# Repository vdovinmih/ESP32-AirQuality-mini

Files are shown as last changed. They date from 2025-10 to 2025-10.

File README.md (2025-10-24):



# ESP32-AirQuality-mini
AirQuality zigbee mini sensor ESP32

Цели и задачи устройства:
1. измерять температуру, влажность, и показатель качества воздуха (TVOС)
2. по протоколу zigbee передавать эти показания в систему умного дома на основе z2m
3. [опция] выступать роутером в zigbee сети
4. [опция] передавать измеренные значения напрямую в устройства одной zigbee сети минуя координатор и сервер умного дома

Основные комплектующие: 
1. ESP32- C6/H2 SuperMini 
https://aliexpress.ru/item/1005006907067134.html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
https://aliexpress.ru/item/1005008148472502.html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
https://github.com/Zektopic/esp32-h2-supermini-kicad?ysclid=memrikceaz898473666
* H2 
https://www.espboards.dev/esp32/esp32-h2-super-mini/
* C6 
https://www.espboards.dev/esp32/esp32-c6-super-mini/

3. Датчик температуры и влажности AHT10 (i2c)
https://aliexpress.ru/item/1005008699139931.html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

4. AGS10 Модуль обнаружения газа (i2c)
https://aliexpress.ru/item/1005008593136272.html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

5. [опция] на площадки модуля B+ B- опционально можно подключить 3.7в LiIon АКБ совмещённый с модулем защиты
https://aliexpress.ru/item/1005004304618610.html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

на модули датчиков питание 3.3в подаётся с ESP32-H2, +2 пина i2c, я использовал (H2 модуль) 13, 14. Но 13 нога висит в паралель с диодом. Лучше использовать другую пару например 11,12
 
Питание устройства:
1. Интегрированный на ESP32 модуле разъём usb-c
2. пара клемм на 12 вольт (при наличии преобразователя 12в -> 5в), опционально делитель для измерения
3. для измерения напряжения батареи нужен делитель. 50/50
4.

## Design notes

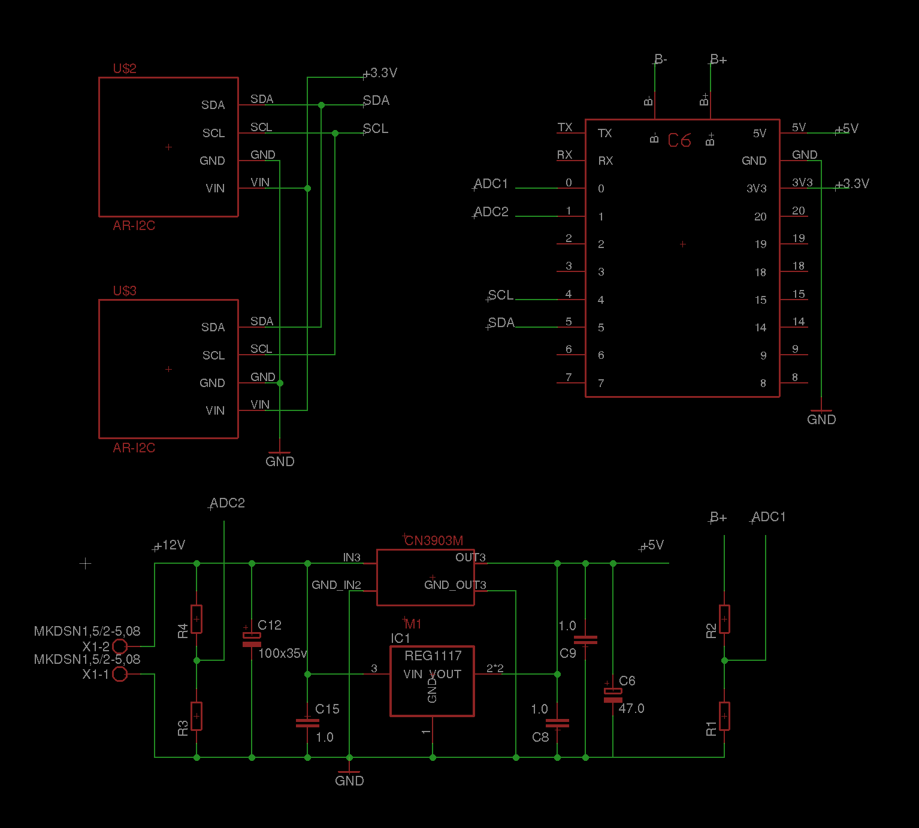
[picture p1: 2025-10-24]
HW/schematic.png

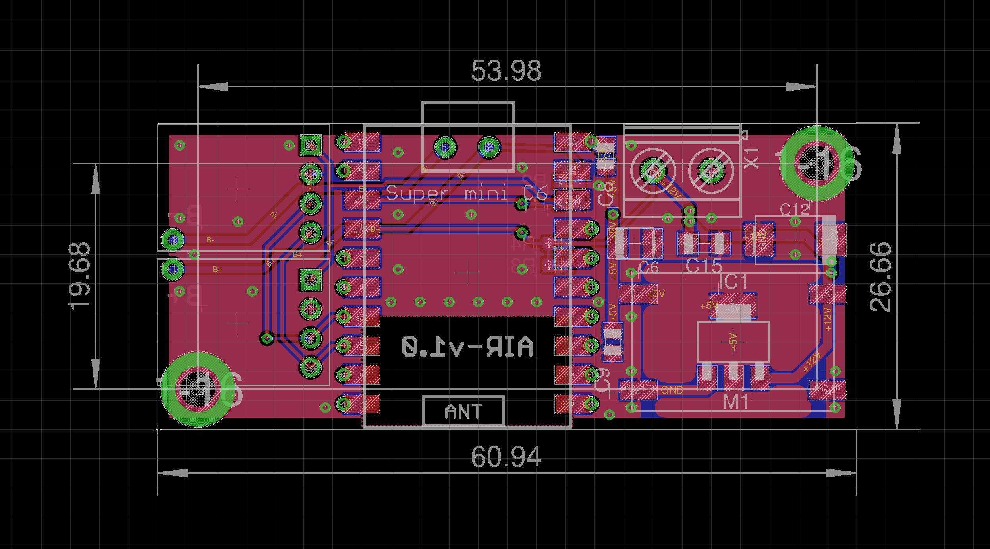
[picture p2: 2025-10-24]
HW/main-v1.0.png

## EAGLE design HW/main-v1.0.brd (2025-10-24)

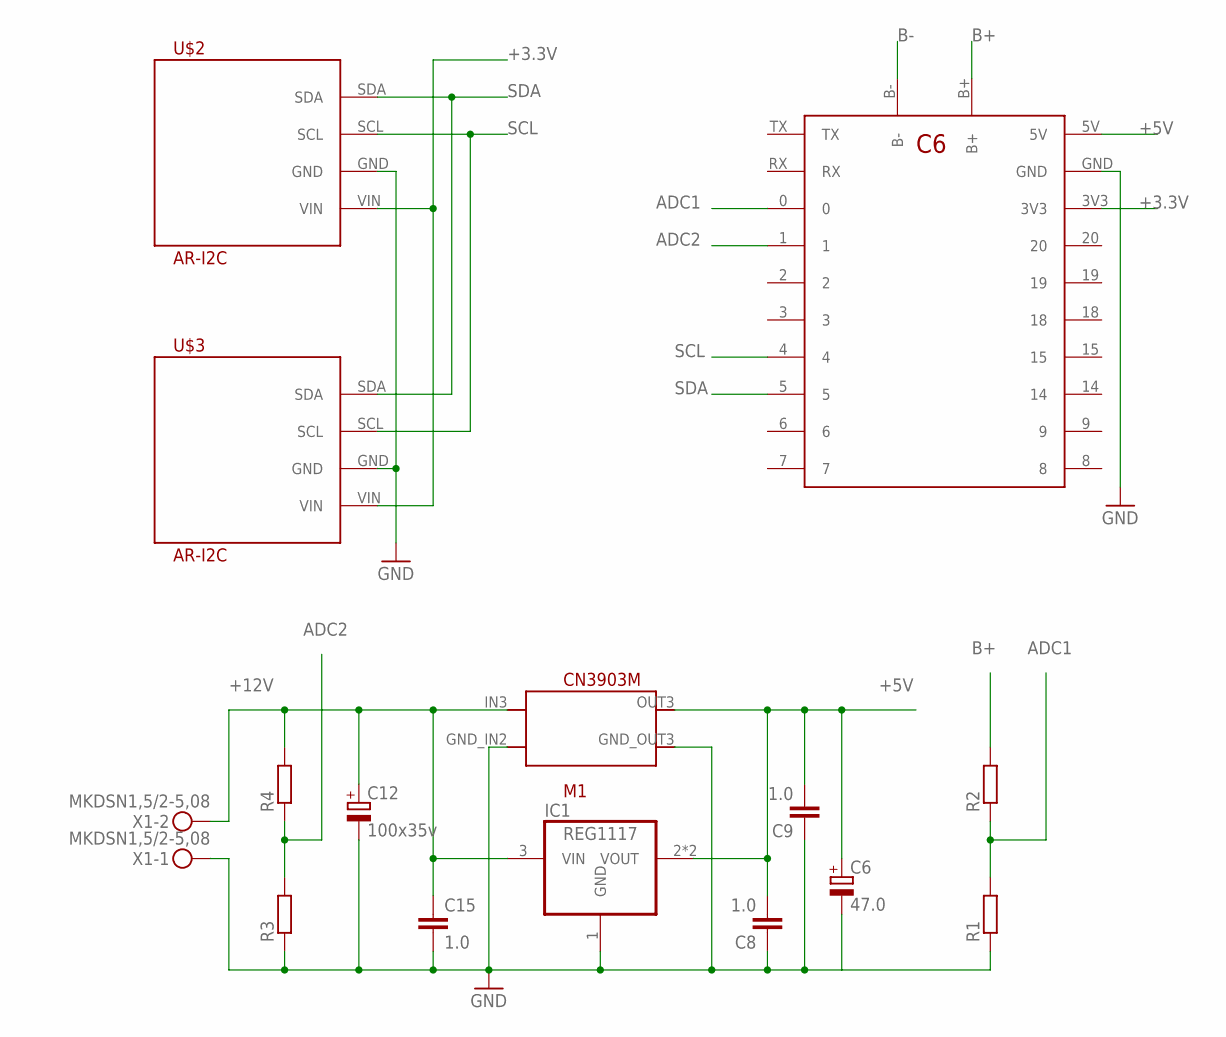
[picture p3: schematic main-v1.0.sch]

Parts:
C6: 47.0; SMC_B
C8, C9: 1.0; C0805
C12: 100x35v; SMC_E
C15: 1.0; C1206
IC1: REG1117; SOT223
M1: CN3903M
R1, R2, R3, R4: R-EU_R0603; R0603
U$1: ESP32-C6-SM; ESP32-C6-SUPER-MINI
U$2, U$3: AR-I2C
X1: MKDSN1,5/2-5,08

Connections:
+3.3V: U$1.3V3, U$2.VIN, U$3.VIN
+5V: C6.+, C8.2, C9.2, IC1.2 (VOUT), IC1.4 (VOUT), M1.OUT3 (OUT), U$1.5V
+12V: C12.+, C15.1, IC1.3 (VIN), M1.IN3 (IN), R4.2, X1.2
ADC1: R1.2, R2.1, U$1.0
ADC2: R3.2, R4.1, U$1.1
B+: R2.2, U$1.B+
B-: U$1.B-
GND: C6.-, C8.1, C9.1, C12.-, C15.2, IC1.1 (GND), M1.GND_IN2 (GND_IN), M1.GND_OUT3 (GND_OUT), R1.1, R3.1, U$1.GND, U$2.GND, U$3.GND, X1.1
SCL: U$1.4, U$2.SCL, U$3.SCL
SDA: U$1.5, U$2.SDA, U$3.SDA

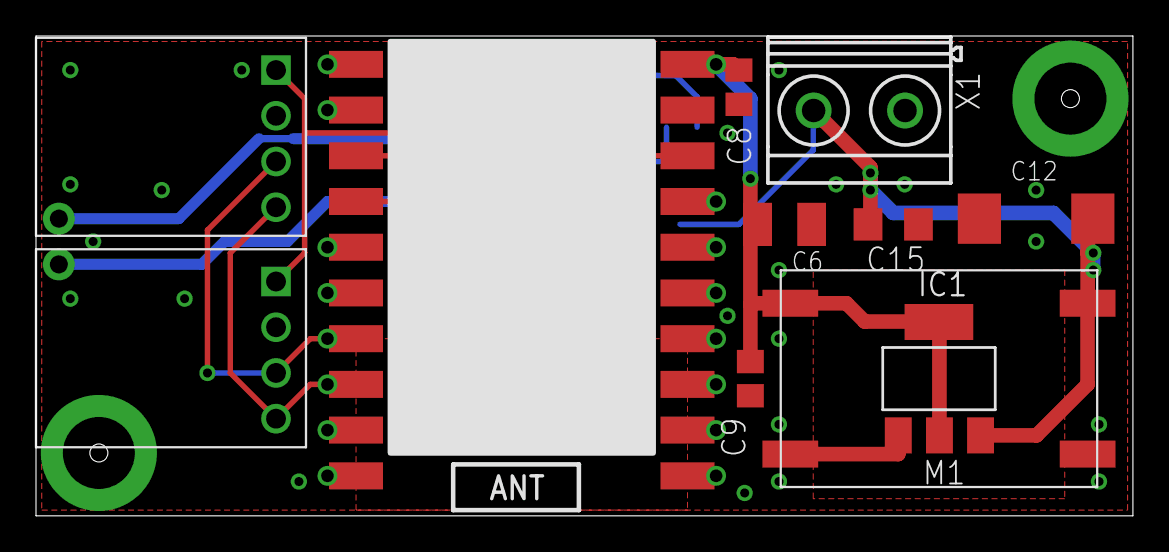
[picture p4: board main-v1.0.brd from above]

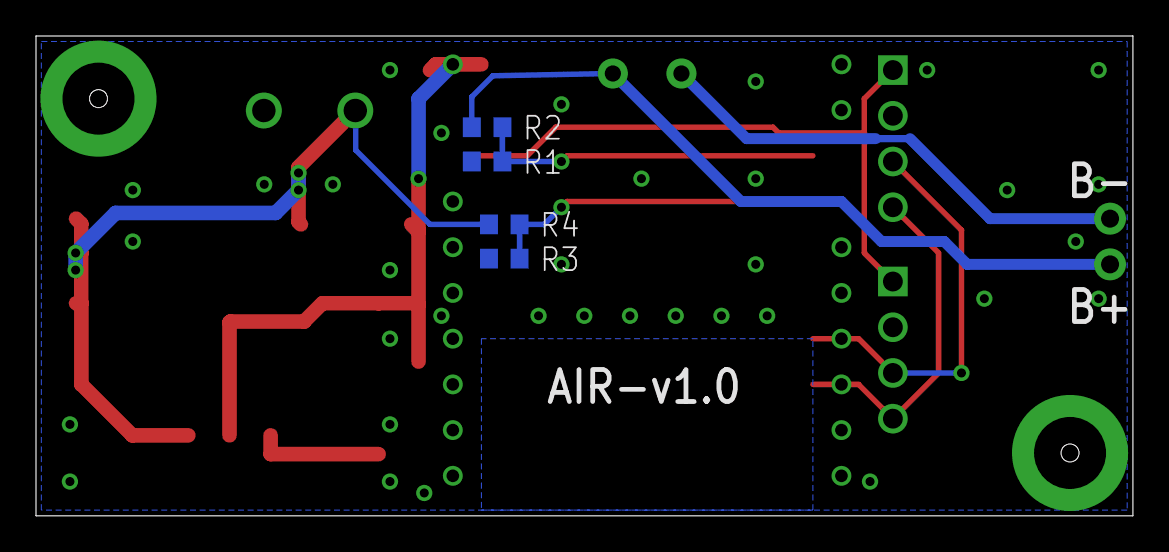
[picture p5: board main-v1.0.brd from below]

Board: 2 copper layers, 60.9 x 26.7 mm, 15 parts (4 on the bottom side), 9 nets.

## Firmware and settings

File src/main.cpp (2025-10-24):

#include "Adafruit_AGS02MA.h"
#include "Adafruit_AHTX0.h"
#include "board_defines.h"
#include "i2c_scaner.h"

constexpr byte TVOC_ADDRESS = 0x1A;
constexpr byte TEMP_ADDRESS = 0x38;

// constexpr byte I2C_SDA = 13, I2C_SCL = 14;

Adafruit_AGS02MA ags;
Adafruit_AHTX0 aht;

#include "Zigbee.h"

/* Zigbee endpints configuration */
#define TEMP_SENSOR_ENDPOINT_NUMBER 10
#define TVOC_SENSOR_ENDPOINT_NUMBER 11
uint8_t button = BOOT_PIN;

// Optional Time cluster variables

float tvoc;
float temperature;
float relative_humidity;


ZigbeeTempSensor zbTempSensor = ZigbeeTempSensor(TEMP_SENSOR_ENDPOINT_NUMBER);
ZigbeeAnalog zbTVOC = ZigbeeAnalog(TVOC_SENSOR_ENDPOINT_NUMBER);

/************************ Temp sensor *****************************/
static void temp_sensor_value_update(void *arg) {
  sensors_event_t humidity, temp;
  for (;;) {
    aht.getEvent(&humidity, &temp);// populate temp and humidity objects with fresh data
    
    temperature = temp.temperature;
    relative_humidity = humidity.relative_humidity;
    tvoc = float(ags.getTVOC());

    Serial.printf("Updated temperature: %.2f°C, Humidity: %.2f%%, TVOC: %.0f\r\n", temperature, relative_humidity, tvoc);

    zbTempSensor.setTemperature(temperature);
    zbTempSensor.setHumidity(relative_humidity);
    zbTVOC.setAnalogInput(tvoc);

    delay(2000);
  }
}

/********************* Arduino functions **************************/
void setup() {
  Serial.begin(115200);

  delay(2000);

  Serial.print("Starting I2C interface...");
  Wire.begin(I2C_SDA, I2C_SCL);
  Serial.println(F("done."));

  I2Cscaner();
  delay(1000);

  ags.begin(&Wire, TVOC_ADDRESS);

  ags.printSensorDetails();
  delay(1000);

  aht.begin(&Wire, TEMP_ADDRESS);
  aht.getTemperatureSensor()->printSensorDetails();
  aht.getHumiditySensor()->printSensorDetails();

  // Init button switch
  pinMode(button, INPUT_PULLUP);

  zbTempSensor.setManufacturerAndModel("Mike_DIY", "AirSensor_v1");
  zbTempSensor.setMinMaxValue(-40, 85);
  zbTempSensor.setTolerance(0.3);

  zbTVOC.addAnalogInput();
  zbTVOC.setAnalogInputMinMax(0, 99999);
  zbTVOC.setAnalogInputResolution(1);
  zbTVOC.setAnalogInputDescription("TVOC (ppb)");

  // Add humidity cluster to the temperature sensor device with min, max and tolerance values
  zbTempSensor.addHumiditySensor(0, 100, 2);

  //Zigbee.setDebugMode(true);

  // Add endpoint to Zigbee Core
  Zigbee.addEndpoint(&zbTempSensor);
  Zigbee.addEndpoint(&zbTVOC);

  Serial.println("Starting Zigbee...");
  // When all EPs are registered, start Zigbee in End Device mode

#ifdef ZIGBEE_MODE_ZCZR
#undef ZIGBEE_MODE_ED
  if (!Zigbee.begin(ZIGBEE_ROUTER)) {
#endif
#ifdef ZIGBEE_MODE_ED
  if (!Zigbee.begin()) {
#endif

    Serial.println("Zigbee failed to start!");
    Serial.println("Rebooting...");
    ESP.restart();
  } else {
    Serial.println("Zigbee started successfully!");
  }
  Serial.println("Connecting to network");
  while (!Zigbee.connected()) {
    Serial.print(".");
    delay(100);
  }
  Serial.println();

  // Start Temperature sensor reading task
  xTaskCreate(temp_sensor_value_update, "temp_sensor_update", 4096, NULL, 10, NULL);
}

void loop() {
  // Checking button for factory reset
  if (digitalRead(button) == LOW) {  // Push button pressed
    // Key debounce handling
    delay(100);
    int startTime = millis();
    while (digitalRead(button) == LOW) {
      delay(50);
      if ((millis() - startTime) > 3000) {
        // If key pressed for more than 3secs, factory reset Zigbee and reboot
        Serial.println("Resetting Zigbee to factory and rebooting in 1s.");
        delay(1000);
        Zigbee.factoryReset();
      }
    }
    zbTempSensor.report();
  }
  delay(100);
}

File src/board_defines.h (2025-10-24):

#define BUILD_TYPE_H2 1 
#define BUILD_TYPE_C6 2

#ifdef BOARD_TYPE

#if BOARD_TYPE == BUILD_TYPE_H2
#pragma message "esp32-h2 stuff happening!"
#define I2C_SDA 13
#define I2C_SCL 14
#endif
#if BOARD_TYPE == BUILD_TYPE_C6
#pragma message "esp32-c6 stuff happening!"
#define I2C_SDA 6
#define I2C_SCL 4
#endif

#endif

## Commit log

2025-10-06 PCB v1.0
    [main-v1.0.brd, main-v1.0.sch]
2025-10-24 add esp32-c6 support
